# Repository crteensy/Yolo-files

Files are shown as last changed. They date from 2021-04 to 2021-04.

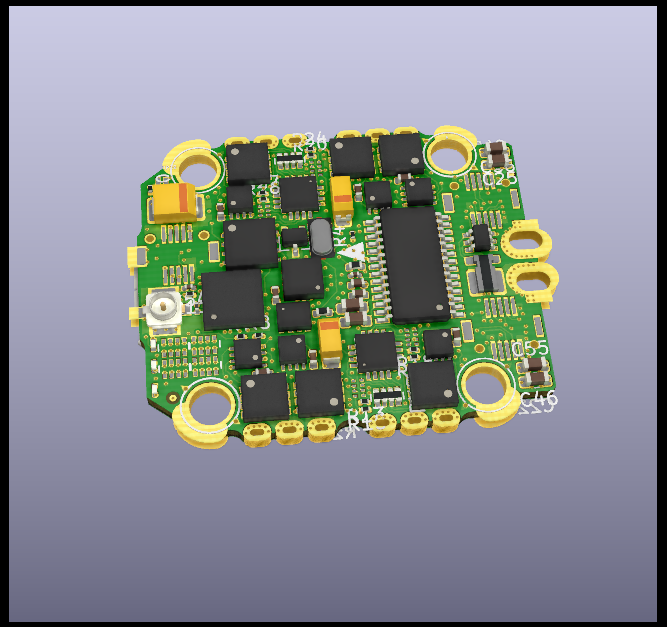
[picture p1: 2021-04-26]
YoloFC-3d-top.png

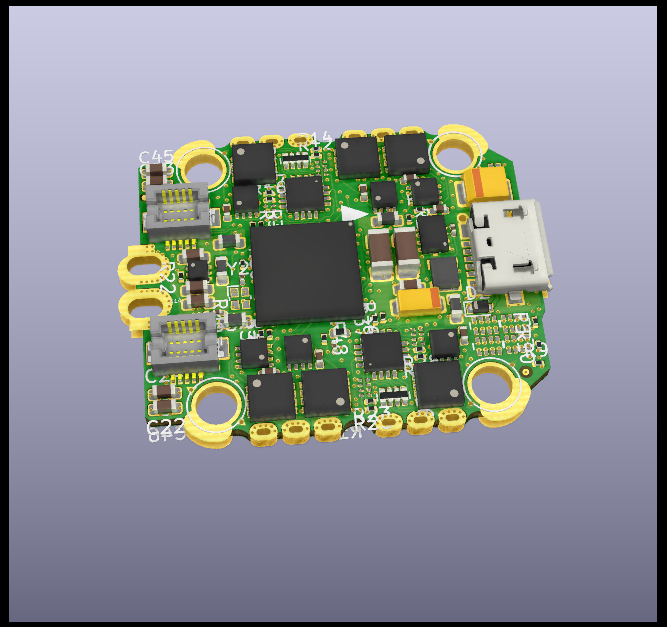
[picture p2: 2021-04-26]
YoloFC-3d-bot.png

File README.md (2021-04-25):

# Yolo-files
This repository contains the currently released files for the Yolo Flight Controller. These include:
- a schematic pdf
- PCB gerber files

The flight controller is not yet ready for production and the design is still a prototype in active development.

If you want to manufacture this FC, we strongly recommend contacting us before: yolofc@weber-ee.de.
If you decide to advertise or sell a product based on this design, please give attribution in the following manner:

Yolo FC - crteensy/chris_fly - https://github.com/crteensy/Yolo-files - CC-BY-SA 4.0

as part of advertising and as part of a shipped product.

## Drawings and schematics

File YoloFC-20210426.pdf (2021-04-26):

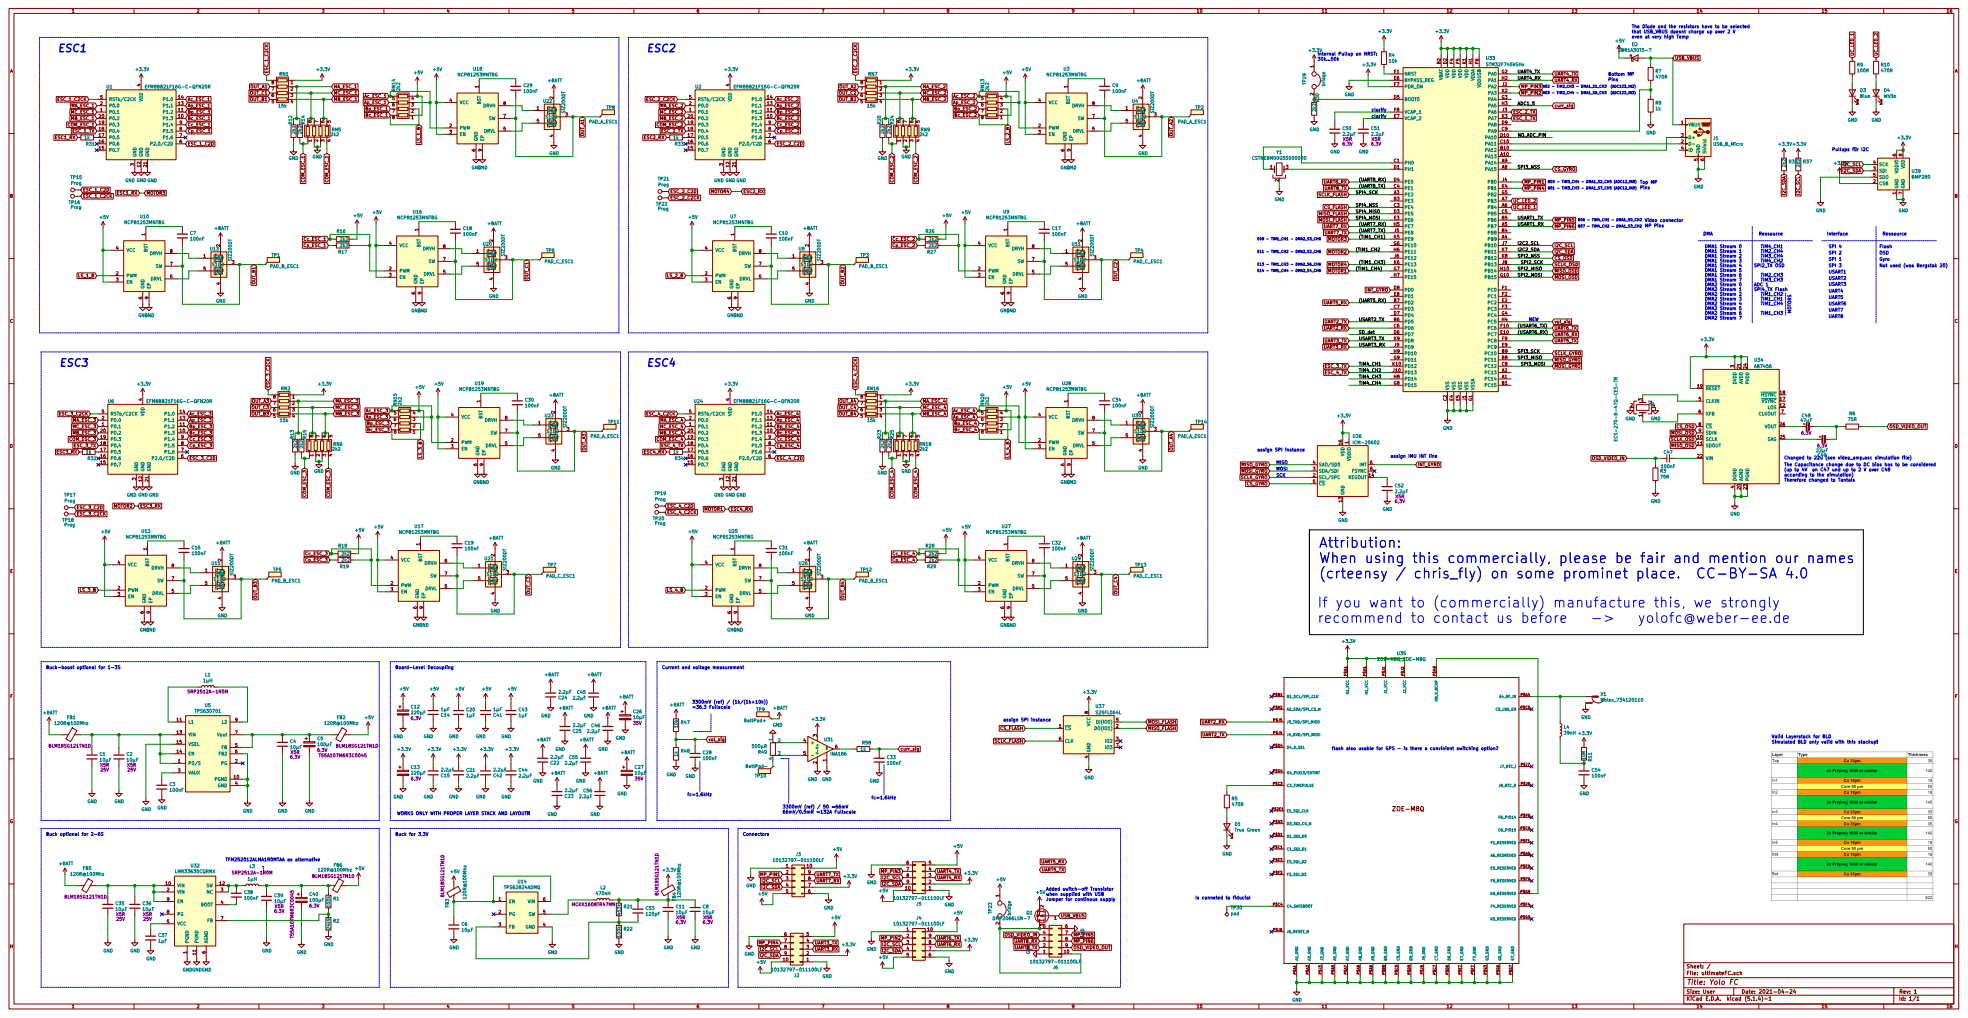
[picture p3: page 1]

The Diode ond the resistors have to be selected
that USB_VBUS doesnt charge up over 2 V
even at very high Temp
D2 SBR1A30T5-7 +5V

1 PWM 2 EN 3 VCC 4 DRVL 5 GND

3 Y24 ECS-270-8-47Q-CES-TR GND

4 RSTb/C2CK 5 P2.0/C2D 6 P1.6 7 P1.5 8 P1.4 9 U6 EFM8BB21F16G-C-QFN20R GND GND GND

4 RSTb/C2CK 5 P2.0/C2D 6 P1.6 7 P1.5 8 P1.4 9 U24 EFM8BB21F16G-C-QFN20R GND GND GND

assign IMU INT line

(up to 4V on C47 und up to 2 V over C48
according to the simulation)
Therefore changed to Tantals

GND
Attribution:
When using this commercially, please be fair and mention our names

(crteensy / chris_fly) on some prominet place. CC-BY-SA 4.0
If you want to (commercially) manufacture this, we strongly
recommend to contact us before -> yolofc@weber-ee.de

Buck-boost optional for 1-3S

Valid Layerstack for BLD
Simulated BLD only valid with this stackup!

flash also usable for GPS - is there a convinient switching option? TFM252012ALMA1R0MTAA as alternative

WORKS ONLY WITH PROPER LAYER STACK AND LAYOUT!!

1 VIN 10 PGND 11 SW 12 VIN 2 NC 3 BOOT 4 VCC 5 AGND

Added switch-off Transistor when supplied with USB
Jumper for continous supply

Is conneted to fiducial

File: ultimateFC.sch Sheet: /
Id: 1/1 Title: Yolo FC

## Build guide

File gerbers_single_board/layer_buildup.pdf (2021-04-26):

### Tabelle1

Layer | Type | Thickness
Top | Cu 35µm | 35
| 2x Prepreg 1080 or similar | 140
In1 | Cu 18µm | 18
| Core 50 μm | 50
In2 | Cu 18µm | 18
| 2x Prepreg 1080 or similar | 140
In3 | Cu 35µm | 35
| Core 50 μm | 50
In4 | Cu 35µm | 35
| 2x Prepreg 1080 or similar | 140
In5 | Cu 18µm | 18
| Core 50 μm | 50
IN6 | Cu 18µm | 18
| 2x Prepreg 1080 or similar | 140
Bot | Cu 35µm | 35

922
